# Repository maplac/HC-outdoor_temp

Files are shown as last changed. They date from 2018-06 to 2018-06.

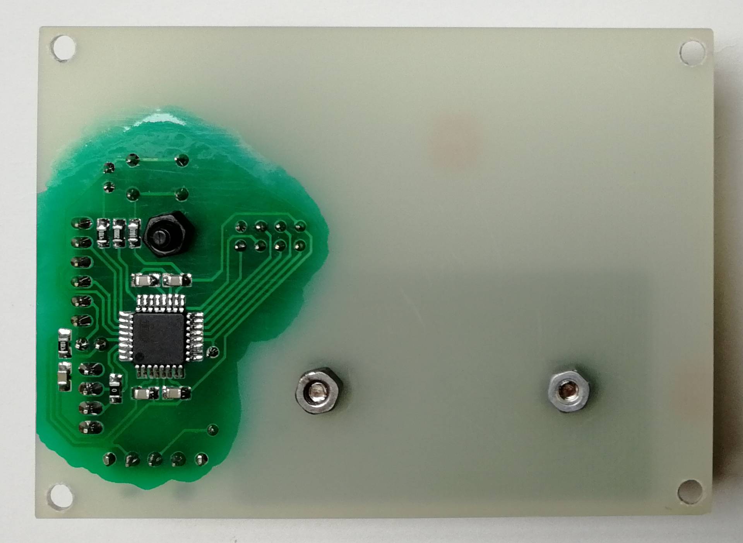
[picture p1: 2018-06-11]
Electronics/pcb_bot.jpg

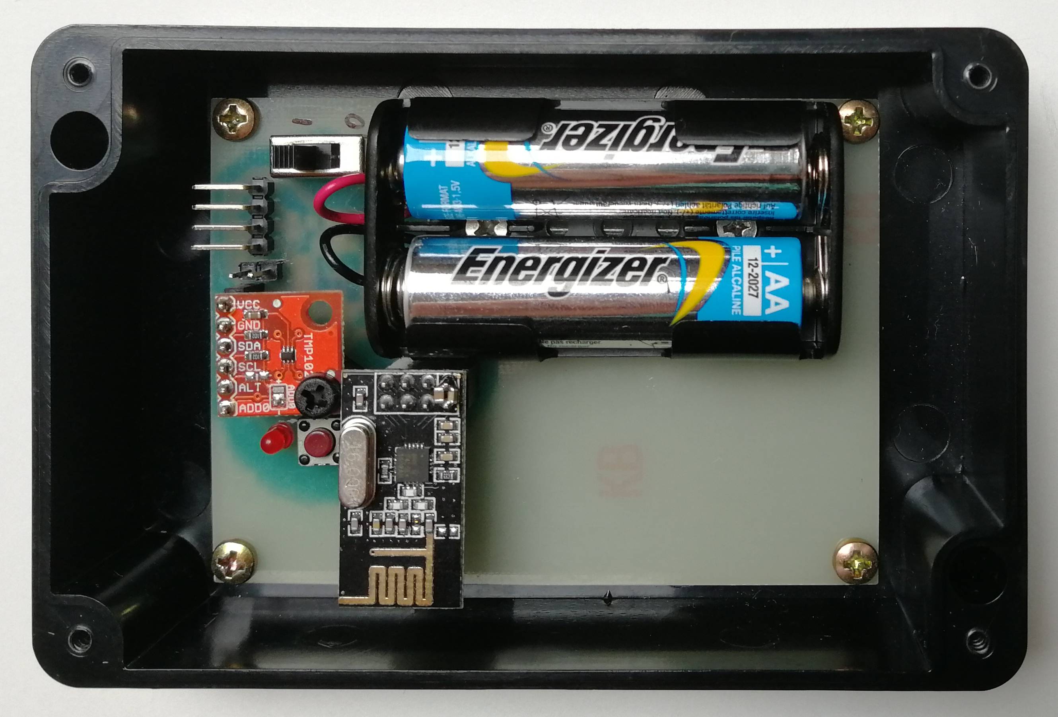
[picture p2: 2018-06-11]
Electronics/pcb_top.jpg

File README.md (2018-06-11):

# HC-outdoor_temp

Nahrání bootloaderu do mikrokontroléru:
1. Do Arduino UNO nahrát ArduinoISP sketch.
2. Signálové a napájecí vodiče propojit, jak je uvedeno v https://www.arduino.cc/en/Tutorial/ArduinoToBreadboard a https://github.com/maplac/HC-outdoor_temp/blob/master/bootloader_connection.jpg.
3. Do Arduino IDE přidat MiniCore https://github.com/MCUdude/MiniCore.
4. Nastavit MiniCore - Board:Atmega328, Bootloader:yes, Variant:328P/328PA, BOD:1,8v, Clock:1 MHz internal, Compiler LTO:Disabled. https://github.com/maplac/HC-outdoor_temp/blob/master/bootloader_ide_settings.jpg
5. Nastavit programátor na "Arduino as ISP" a spustit Burn Bootloader.

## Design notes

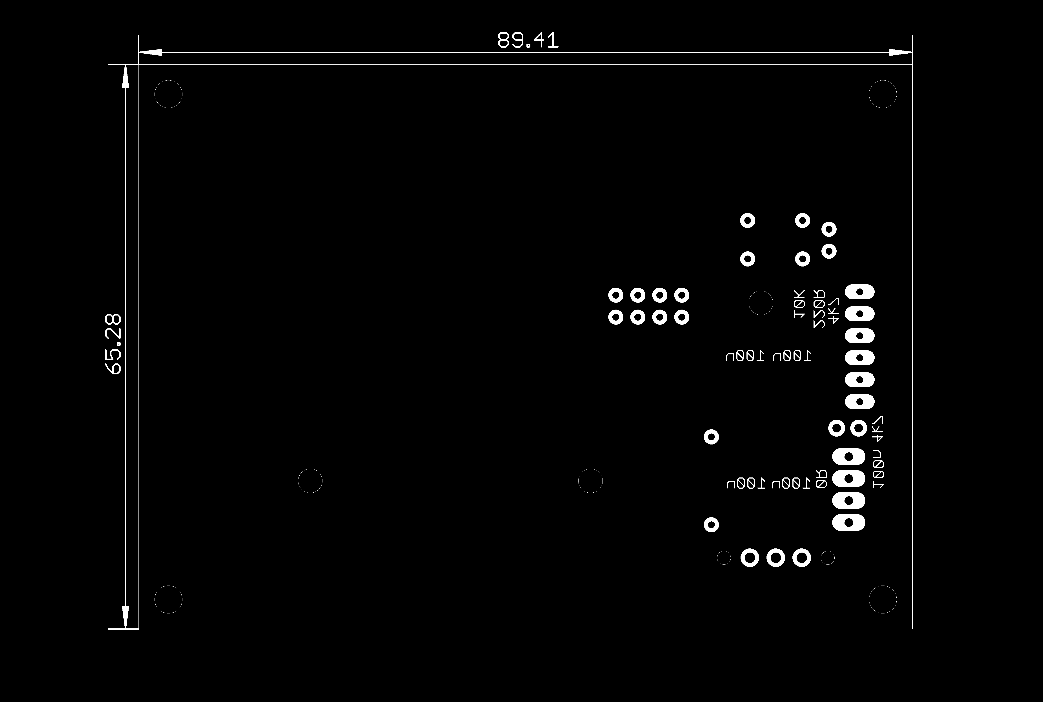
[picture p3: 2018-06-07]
Electronics/values_bot.png

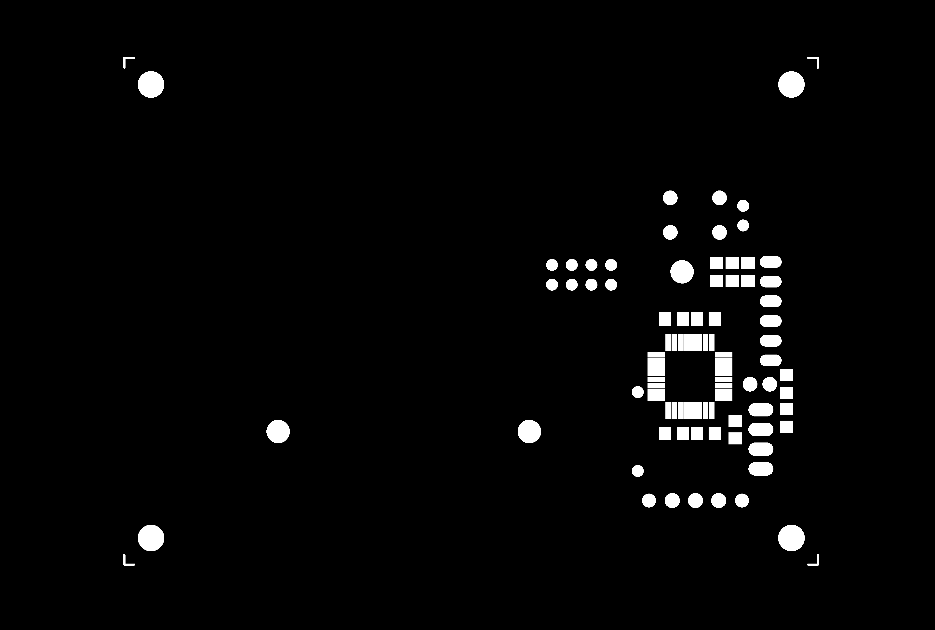
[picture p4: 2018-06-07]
Electronics/mask_bot.png

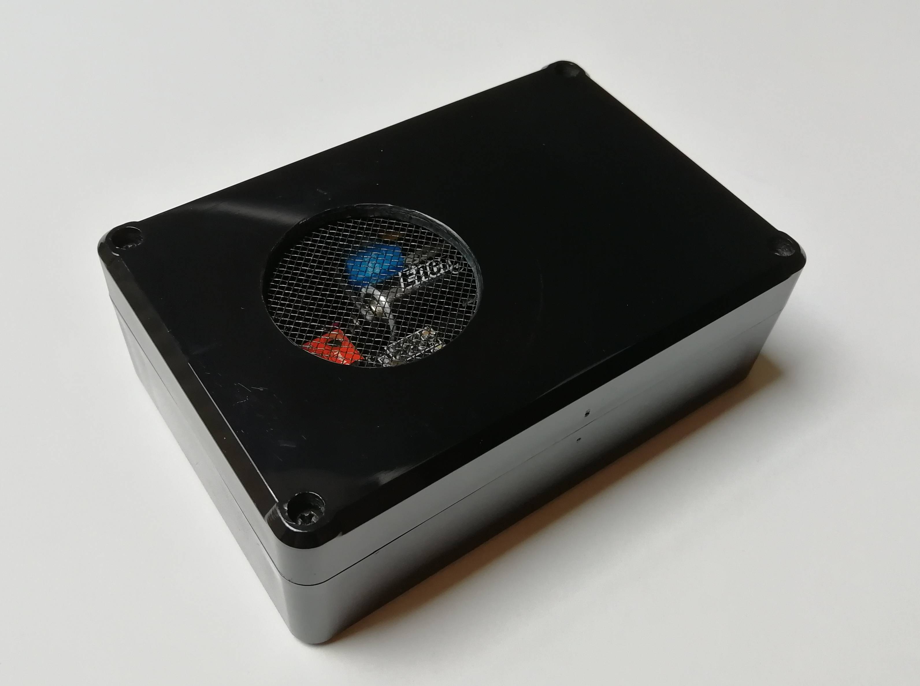
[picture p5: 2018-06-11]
Electronics/finished_device.jpg

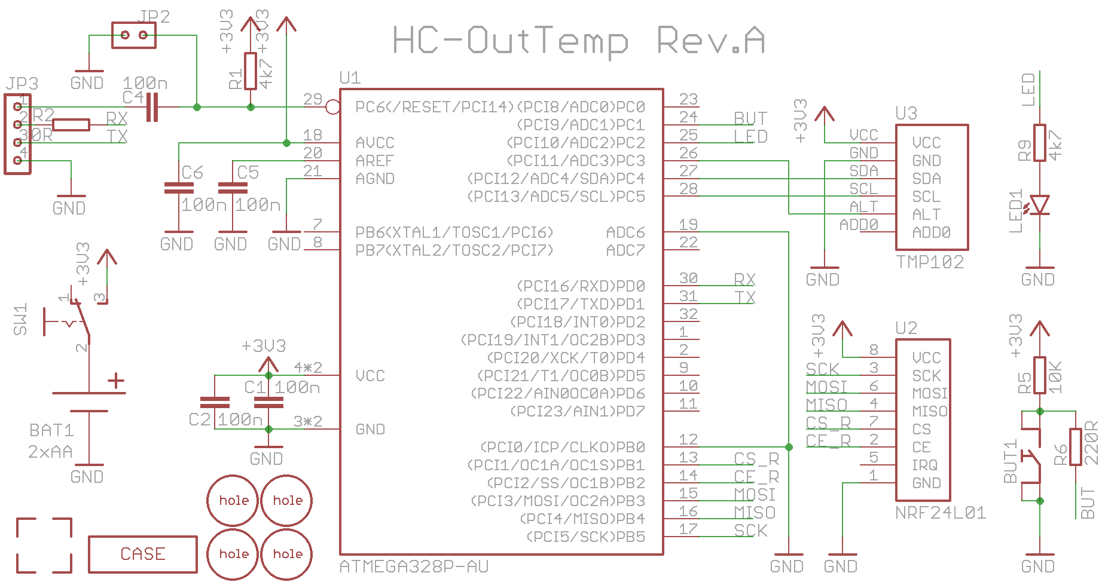
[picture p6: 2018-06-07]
Electronics/schematics.png

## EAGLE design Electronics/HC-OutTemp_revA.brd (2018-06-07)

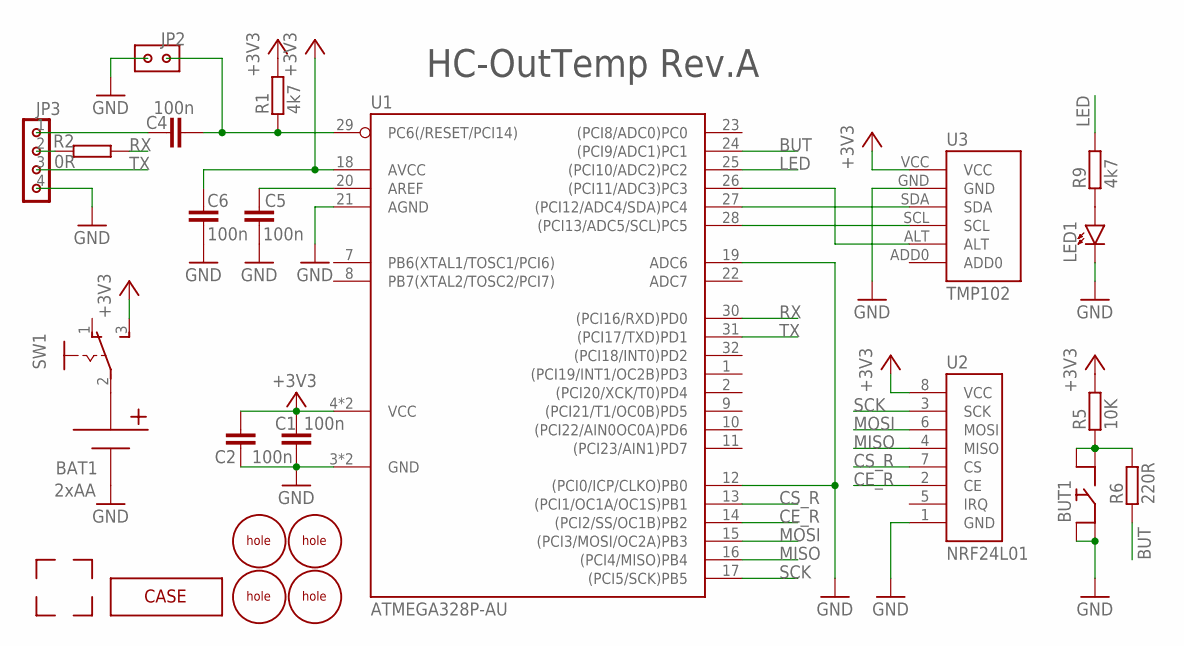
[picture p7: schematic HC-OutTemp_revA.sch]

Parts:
BAT1: 2xAA; 2XAA_BATTERY_HOLDER
BUT1: BUTTON'THT'; BUTTON
C1, C2, C4, C5, C6: 100n; C0805
JP2: PINHD2X1; PINHD-2X1
JP3: PINHD3X1; PINHD-4X1-90
LED1: LED'3MM'; LED3MM
R1, R9: 4k7; R0805
R2: 0R; R0805
R5: 10K; R0805
R6: 220R; R0805
SW1: SWITCH_SLIDE; SLIDE_SWITCH
U1: ATMEGA328P-AU; QFP80P900X900X120-32N
U2: NRF24L01
U3: TMP102
U$1, U$2, U$3, U$4: CORNER
U$5, U$6, U$7, U$8: HOLE
U$9: CASE'120X80X40'; CASE-120X80X40

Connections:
+3V3: C1.2, C2.2, C6.2, R1.2, R5.2, SW1.3 (S), U1.4 (VCC), U1.6 (VCC), U1.18 (AVCC), U2.8 (VCC), U3.VCC
BUT: R6.1, U1.24 ((PCI9/ADC1)PC1)
CE_R: U1.14 ((PCI2/SS/OC1B)PB2), U2.2 (CE)
CS_R: U1.13 ((PCI1/OC1A/OC1S)PB1), U2.7 (CS)
GND: BAT1.N, BUT1.2, BUT1.4, C1.1, C2.1, C5.2, C6.1, JP2.1, JP3.4, LED1.K, U1.3 (GND), U1.5 (GND), U1.12 ((PCI0/ICP/CLKO)PB0), U1.19 (ADC6), U1.21 (AGND), U2.1 (GND), U3.GND
LED: R9.2, U1.25 ((PCI10/ADC2)PC2)
MISO: U1.16 ((PCI4/MISO)PB4), U2.4 (MISO)
MOSI: U1.15 ((PCI3/MOSI/OC2A)PB3), U2.6 (MOSI)
unnamed: BAT1.P, SW1.2 (MIDDLE)
unnamed: C4.1, JP2.2, R1.1, U1.29 (PC6(/RESET/PCI14))
unnamed: LED1.A, R9.1
unnamed: U1.26 ((PCI11/ADC3)PC3), U3.ALT
unnamed: C5.1, U1.20 (AREF)
unnamed: C4.2, JP3.1
unnamed: BUT1.1, BUT1.3, R5.1, R6.2
unnamed: JP3.2, R2.2
unnamed: U1.27 ((PCI12/ADC4/SDA)PC4), U3.SDA
unnamed: U1.28 ((PCI13/ADC5/SCL)PC5), U3.SCL
RX: R2.1, U1.30 ((PCI16/RXD)PD0)
SCK: U1.17 ((PCI5/SCK)PB5), U2.3 (SCK)
TX: JP3.3, U1.31 ((PCI17/TXD)PD1)

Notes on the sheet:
HC-OutTemp Rev.A

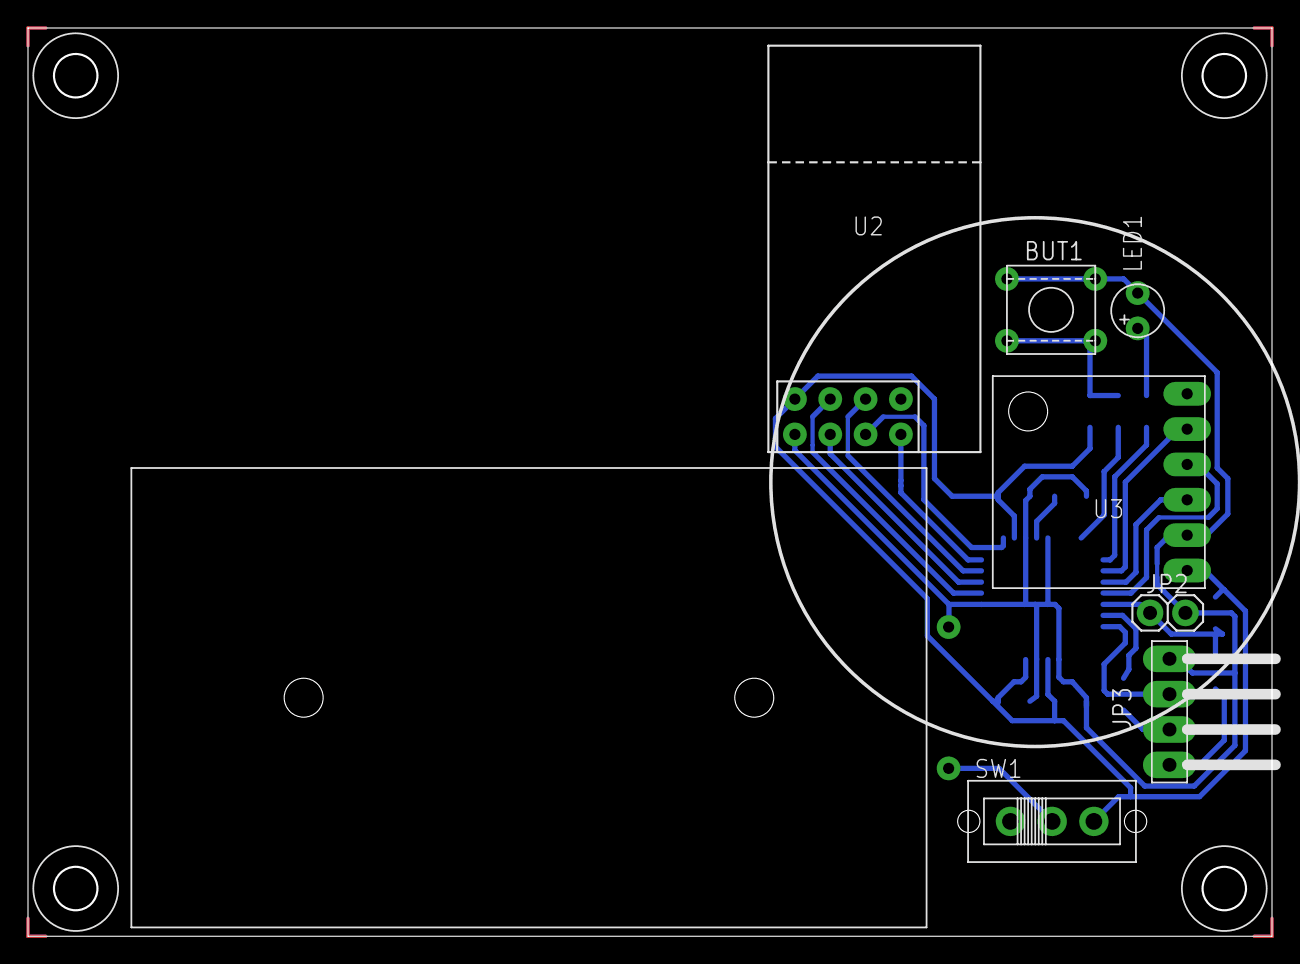
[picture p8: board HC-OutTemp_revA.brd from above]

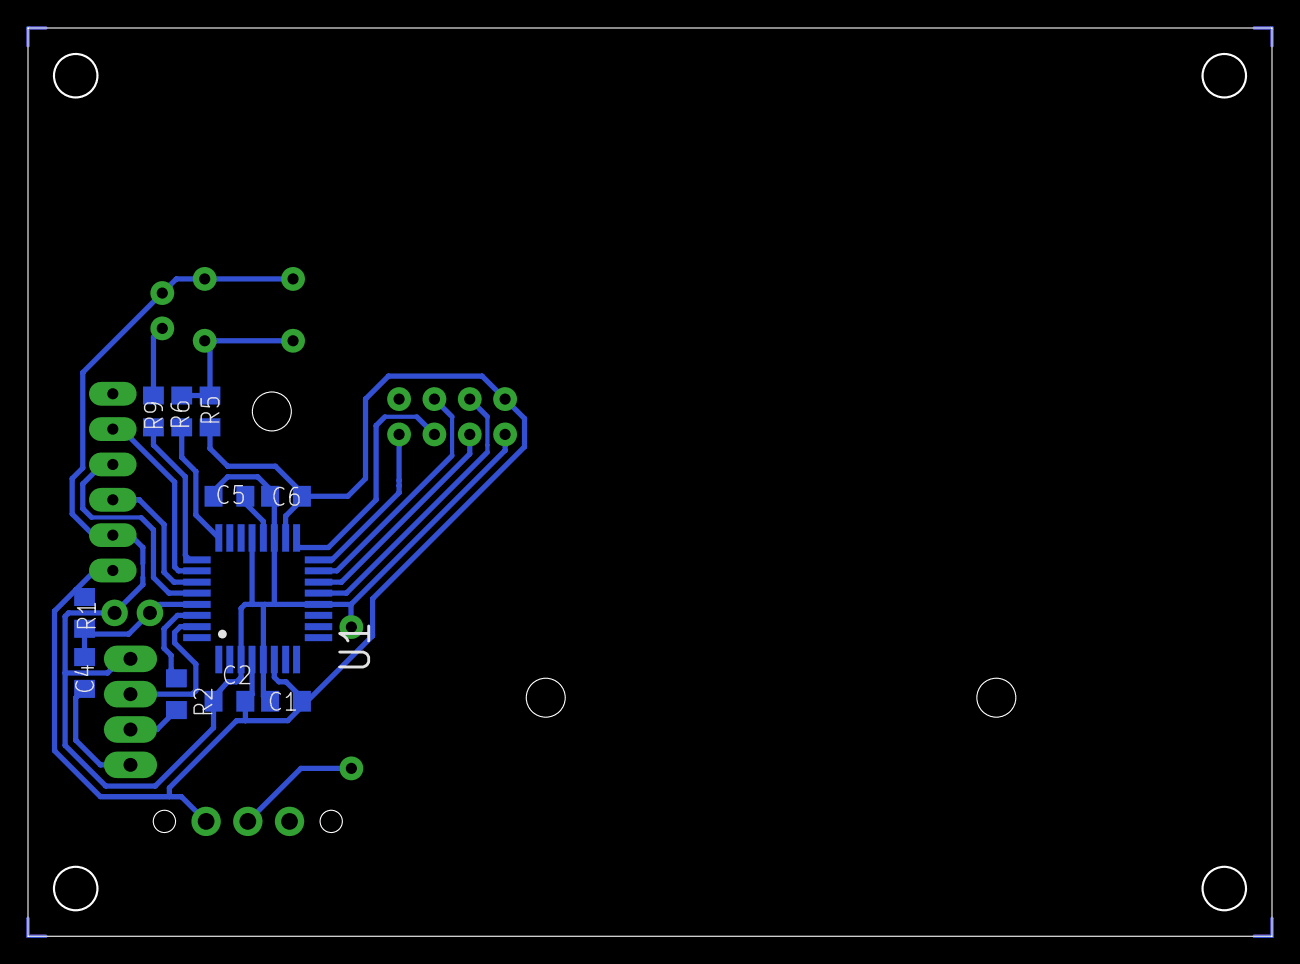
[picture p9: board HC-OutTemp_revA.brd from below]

Board: 2 copper layers, 89.4 x 65.3 mm, 28 parts (11 on the bottom side), 21 nets.

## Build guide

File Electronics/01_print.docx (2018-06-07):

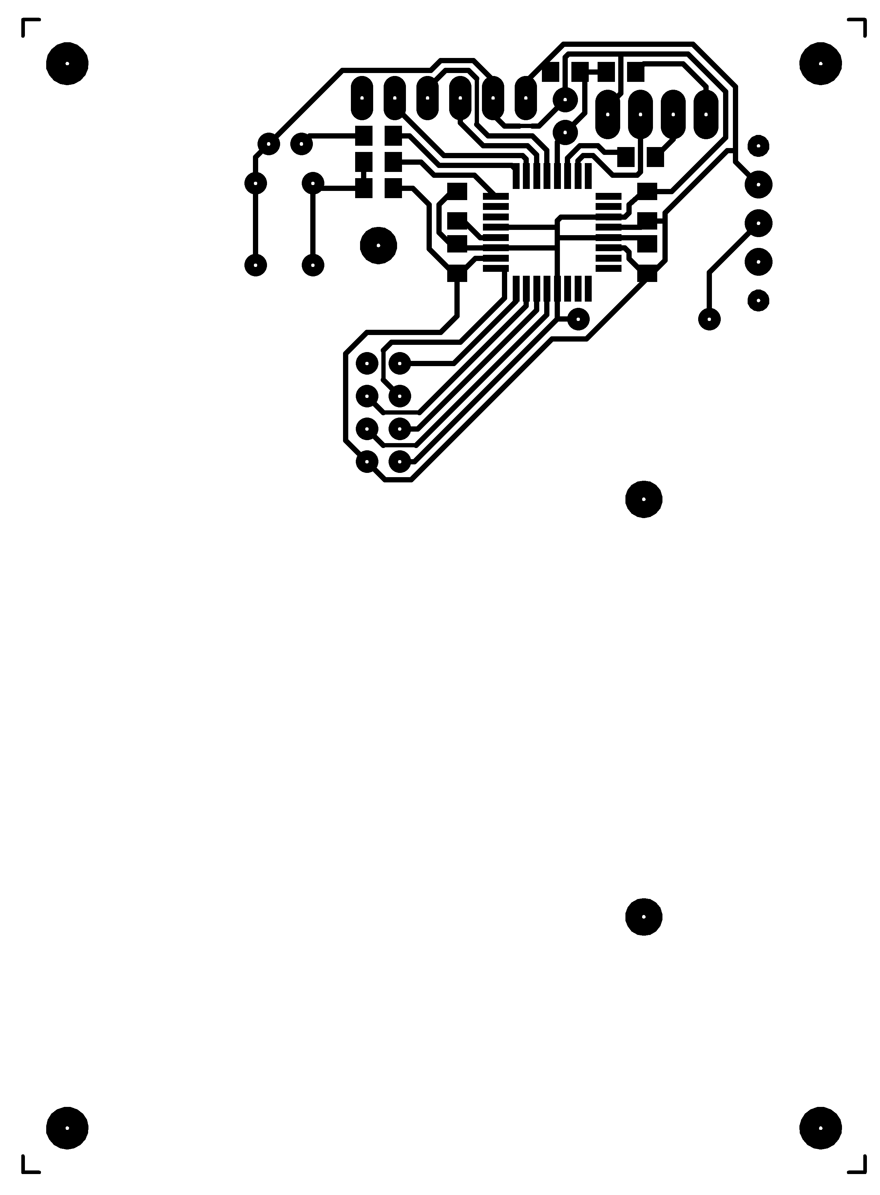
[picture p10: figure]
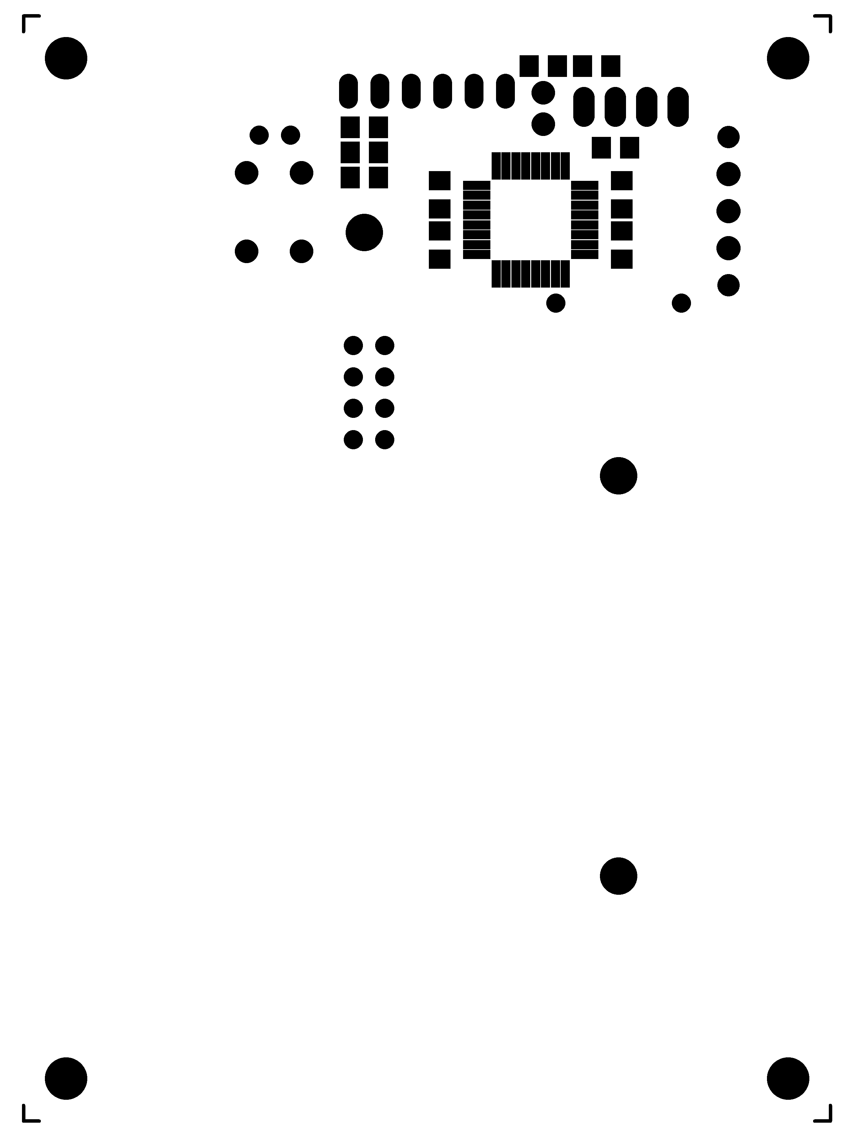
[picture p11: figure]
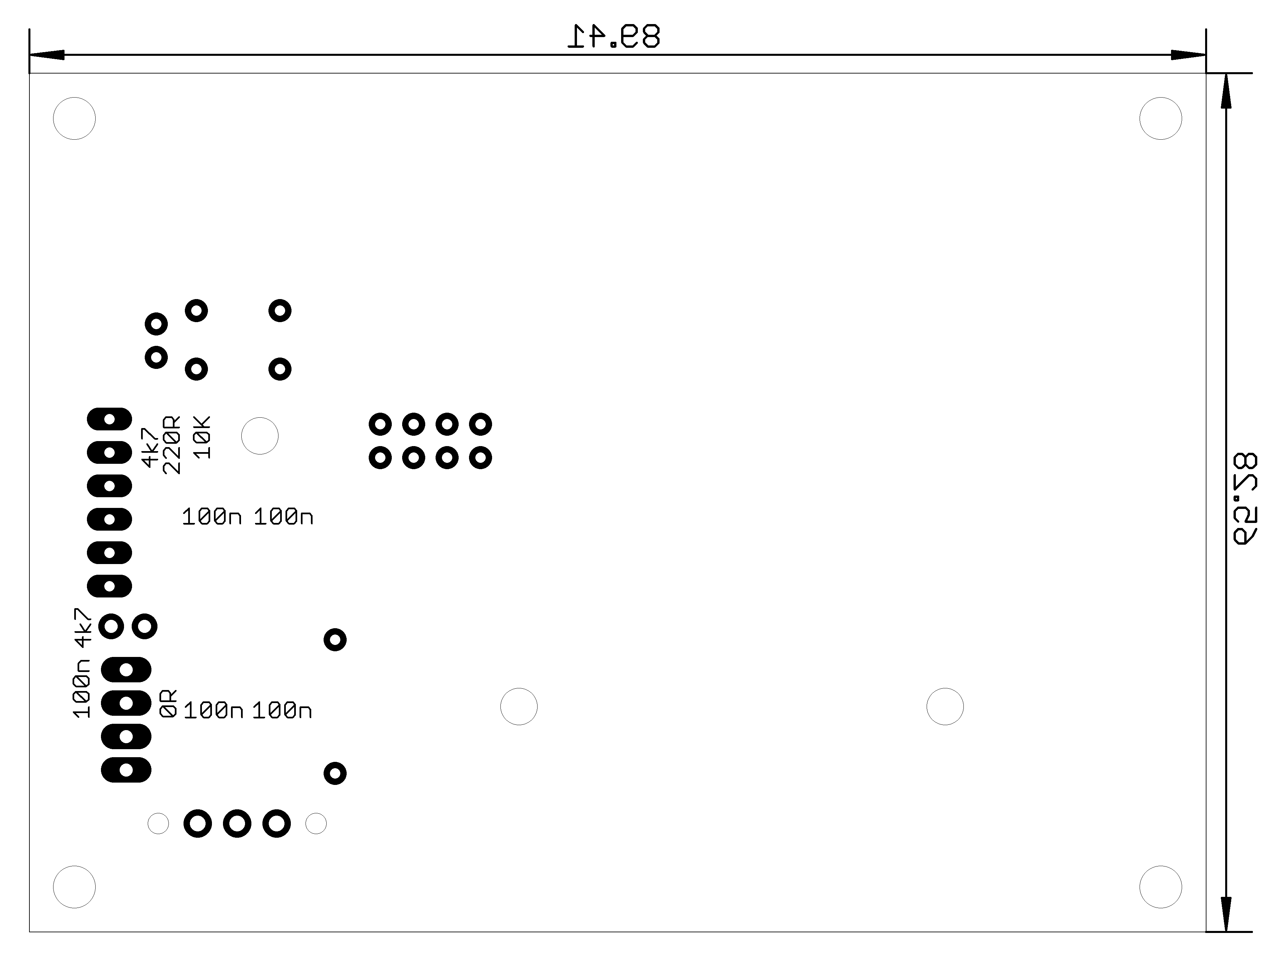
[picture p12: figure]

Qty Value Device Package Parts Description

1 LED'3MM' LED3MM LED1

1 0R R'2' R0805 R2

5 100n C-CERAMIC'SMD' C0805 C1, C2, C4, C5, C6

1 10K R'2' R0805 R5

1 220R R'2' R0805 R6

1 2xAA BATTERY_1X'DOUBLE' 2XAA_BATTERY_HOLDER BAT1

2 4k7 R'2' R0805 R1, R9

1 ATMEGA328P-AU ATMEGA328P-AU QFP80P900X900X120-32N U1 8-bit Microcontroller with In-System Programmable Flash

1 BUTTON'THT' BUTTON'THT' BUTTON BUT1

1 CASE'120X80X40' CASE'120X80X40' CASE-120X80X40 U$9

4 CORNER CORNER CORNER U$1, U$2, U$3, U$4

4 HOLE HOLE HOLE U$5, U$6, U$7, U$8

1 NRF24L01 NRF24L01 NRF24L01 U2

1 PINHD2X1 PINHD-2X1 PINHD-2X1 JP2

1 PINHD3X1 PINHD-4X1 PINHD-4X1-90 JP3 PIN HEADER

1 SWITCH_SLIDE SWITCH_SLIDE SLIDE_SWITCH SW1

1 TMP102 TMP102 TMP102 U3

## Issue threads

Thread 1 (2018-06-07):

Button is connected to a wrong pin

maplac, 2018-06-07:
The button must be connected to pin 1 (INT1) or pin 32 (INT0).

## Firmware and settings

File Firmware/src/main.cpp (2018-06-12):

#ifdef F_CPU
#undef F_CPU
#endif
#define F_CPU 1000000L

#include <Arduino.h>
#include <stdint.h>
#include "printf.h"

#include <SPI.h>
#include <Wire.h>
#include <Ports.h>
#include <nRF24L01.h>
#include <RF24.h>
#include "SparkFunTMP102.h"
#include "Vcc.h"

#define DEVICE_ID       2
//#define DEBUG_ENABLED   1

TMP102 sensor0(0x48);

RF24 radio(10, 9); // Set up nRF24L01 radio on SPI bus (CE, CS)
//const uint64_t pipes[2] = { 0xF0F0F0F0E1LL, 0xF0F0F0F0D2LL };
const uint64_t pipeAddress = 0xF0F0F0F0D2LL;//0xF0F0F0F0E1LL;

const float VccCorrection = 3.16/3.215;  // Measured Vcc by multimeter divided by reported Vcc
Vcc vcc(VccCorrection);

// mcu pins
// const int pinAnalog = 0;
const int pinButton = 3;
const int pinLed = 16;
uint16_t counter = 0;

float voltage;
float temperature1;
float temperature2;

// flags
volatile bool isTimeout = false;
volatile bool isButton = false;

uint8_t counterPackets = 0;
uint32_t counterSendAttempts = 0;
uint32_t counterSendFailed = 0;
char packet[32];

void doMeasure(void);
bool doSend(void);

ISR(WDT_vect) {
  Sleepy::watchdogEvent();
  isTimeout = true;
}

void buttonInt(void){
  isButton = true;
}

void setup() {

  pinMode(pinButton, INPUT);
  pinMode(pinLed, OUTPUT);
  digitalWrite(pinLed, LOW);
  attachInterrupt(digitalPinToInterrupt(pinButton), buttonInt, RISING );

  #ifdef DEBUG_ENABLED
    Serial.begin(9600);
    printf_begin();
  #endif

  radio.begin();
  // optionally, increase the delay between retries & # of retries
  radio.setRetries(15,15);
  // optionally, reduce the payload size.  seems to improve reliability
  //radio.setPayloadSize(8);
  // Open 'our' pipe for writing
  radio.openWritingPipe(pipeAddress);
  // Open the 'other' pipe for reading, in position #1 (we can have up to 5 pipes open for reading)
  //radio.openReadingPipe(1,pipes[1]);
  //radio.openWritingPipe(pipes[1]);
  //radio.openReadingPipe(1,pipes[0]);
  radio.startListening();
  radio.stopListening();

  #ifdef DEBUG_ENABLED
    radio.printDetails();
  #endif

  uint8_t registerByte[2];
  #ifdef DEBUG_ENABLED

    sensor0.openPointerRegister(0x01);// config register
    registerByte[0] = sensor0.readRegister(0);
    registerByte[1] = sensor0.readRegister(1);
    // Serial.print("TMP102 config register: ");
    // Serial.print(registerByte[0]);
    // Serial.print(" ");
    // Serial.println(registerByte[1]);
  #endif

  // Initialize sensor0 settings
  // These settings are saved in the sensor, even if it loses power
  sensor0.begin();  // Join I2C bus
  // set the number of consecutive faults before triggering alarm.
  // 0-3: 0:1 fault, 1:2 faults, 2:4 faults, 3:6 faults.
  sensor0.setFault(0);  // Trigger alarm immediately
  // set the polarity of the Alarm. (0:Active LOW, 1:Active HIGH).
  sensor0.setAlertPolarity(1); // Active HIGH
  // set the sensor in Comparator Mode (0) or Interrupt Mode (1).
  sensor0.setAlertMode(1); // Comparator Mode.
  // set the Conversion Rate (how quickly the sensor gets a new reading)
  //0-3: 0:0.25Hz, 1:1Hz, 2:4Hz, 3:8Hz
  sensor0.setConversionRate(0);
  //set Extended Mode.
  //0:12-bit Temperature(-55C to +128C) 1:13-bit Temperature(-55C to +150C)
  sensor0.setExtendedMode(0);
  //set T_HIGH, the upper limit to trigger the alert on
  sensor0.setHighTempC(80); // set T_HIGH in C
  //set T_LOW, the lower limit to shut turn off the alert
  sensor0.setLowTempC(-40); // set T_LOW in C
  sensor0.sleep();

  #ifdef DEBUG_ENABLED
    sensor0.openPointerRegister(0x01);// config register
    registerByte[0] = sensor0.readRegister(0);
    registerByte[1] = sensor0.readRegister(1);
    // Serial.print("TMP102 config register: ");
    // Serial.print(registerByte[0]);
    // Serial.print(" ");
    // Serial.println(registerByte[1]);
  #endif

  voltage = 1.5;
  temperature1 = -1000;
  temperature2 = -1000;

  // analogReference(DEFAULT);//EXTERNAL

  isTimeout = true;
  isButton = false;
  counterPackets = 0;
}

void loop() {
// while(true){
//   digitalWrite(pinLed, HIGH);
//   Sleepy::loseSomeTime(500);
//   digitalWrite(pinLed, LOW);
//   Sleepy::loseSomeTime(500);
// }

  // make sure everything is finished before go to sleep
  delay(40);

  // got to sleep if nothing happend during last loop
  if (!isButton && !isTimeout){
    // wait for button press or measure timer
    Sleepy::loseSomeTime(60000);
  }

  // button was pressed or released
  if(isButton){
    doMeasure();
    bool sendOk = doSend();
    digitalWrite(pinLed, HIGH);
    Sleepy::loseSomeTime(30);
    digitalWrite(pinLed, LOW);
    if(!sendOk){
      Sleepy::loseSomeTime(200);
      digitalWrite(pinLed, HIGH);
      Sleepy::loseSomeTime(30);
      digitalWrite(pinLed, LOW);
    }
    isButton = false;
    isTimeout = false;
  }

  // measuring period timer
  if(isTimeout){
    doMeasure();
    doSend();
    digitalWrite(pinLed, HIGH);
    Sleepy::loseSomeTime(30);
    digitalWrite(pinLed, LOW);
    isTimeout = false;
  }

}

void doMeasure(void){
  // read battery voltage
  //voltage = analogRead(pinAnalog) * 3.3 / 1024.0;

  #ifdef DEBUG_ENABLED
    Serial.print("Temperature: ");
  #endif

  voltage = vcc.Read_Volts();

  // read temperature data
  sensor0.oneShot();
  Sleepy::loseSomeTime(50);
  temperature1 = sensor0.readTempC();

  #ifdef DEBUG_ENABLED
    Serial.print(temperature1);
    if(temperature2 > -100){
      Serial.print(", ");
      Serial.print(temperature2);
    }
    Serial.println(" ");
    Serial.print("Voltage: ");
    Serial.println(voltage);
  #endif
}

bool doSend(void){

  packet[0] = DEVICE_ID; // id
  packet[1] = counterPackets; // packet counter
  packet[2] = 0; // packet type
  packet[3] = 0; // reserved

  float *packetF = (float*) &packet; //size_of(float)=4
  packetF[1] = voltage;
  packetF[2] = temperature1;
  packetF[3] = temperature2;
  //packetF[5] = temperature4;

  uint32_t *packetUI23 = (uint32_t*) &packet;
  packetUI23[4] = counterSendFailed;

  #ifdef DEBUG_ENABLED
    Serial.print("counter = ");
    Serial.print(counterPackets);
  #endif

  bool isSendOk = radio.write( &packet, 32 );
  counterPackets++;
  if(counterPackets == 0){
    counterPackets = 1;
  }
  counterSendAttempts++;
  if (!isSendOk){
    counterSendFailed++;
    #ifdef DEBUG_ENABLED
      Serial.print(", counterFailed = ");
      Serial.print(counterSendFailed);
    #endif
  }

  radio.startListening();
  radio.stopListening();

  #ifdef DEBUG_ENABLED
    // Serial.println("\n=========================================");
  #endif

  return isSendOk;
}

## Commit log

2018-02-11 added: circuit diagram
    [HC-OutTemp_revA.brd, HC-OutTemp_revA.sch]
2018-02-17 changed: firmware - temperature reading and data transfer
2018-05-20 added: libraries for reading sensor TMP102 and for reading power supply voltage
2018-05-25 changed: PCB
    [HC-OutTemp_revA.brd, HC-OutTemp_revA.sch]
2018-05-31 changed: MCU package to SMD
    [HC-OutTemp_revA.brd, HC-OutTemp_revA.sch]
2018-06-02 modified: PCB
    [HC-OutTemp_revA.brd, HC-OutTemp_revA.sch]
2018-06-07 added: exported files for PCB manufacturing
2018-06-11 added: pictures of finished and populated PCB
2018-06-12 modified: the LED blinks twice if the transmission fails
    [main.cpp]
